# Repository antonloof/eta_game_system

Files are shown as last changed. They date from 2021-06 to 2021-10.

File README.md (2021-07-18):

# Eta game system
Playing games on a wall of TLS3001. Driven by a raspberry pi pico

## important docs
https://github.com/FastLED/FastLED/issues/1

Summary:
Manchester encoded data:
1 => 10
0 => 01
Timing is critical, keep constant period!
When sleeping put data low!

Sync frame: "1"*15+"0001"+"0"*11
(111111111111111000100000000000)

Reset frame: "1"*15 + "0100"
(1111111111111110100)

Data frame header: "1"*15 + "0010" 
(1111111111111110010)

Data content: "0"+"x"*12 + "0"+"x"*12 + "0"+"x"*12
where x is the rgb data to send total 39 bits per led
repeat this for all leds in series

The source:
Data communication protocol: 

Gave SDI input signal pin must follow the following definitions:

a. valid input data must be Manchester encoded signal. 

(from high to low transition indicates "1", from low to high Jump indicates "0")

b. During chip power after a synchronization frame must be sent to the chip detection of communication baud rate. Sync frame

Format is: 15'b111111111111111 + 4' b0001 +11' b00000000000, sending synchronization

Frame must be delayed for some time and then send the data frame, so that each chip can be done in order to accurately detect

To the communication baud rate, delay time (us) greater than: Connection chip count ÷ communication baud rate (MHz) × 30

c. several frames in the transmission data, re-send a reset frame, wait 1ms later, send it again with the

Step frames for the chip to eliminate the accumulated error, reset frame format:

15'b111111111111111 +4' b0100

d. data frame format is: 15'b111111111111111 +4' b0010 (header) + first chip

39bit second chip 39bit data + data + ...... + n-th chip 39bit data

e. first chip is first received data chips, chip data format is: 1 'b0 (identification bits) + 12'

bxxxxxxxxxxxx (output port 1 data) + 1'b0 (flag) + 12'bxxxxxxxxxxxx (input

The port 2 data) + 1'b0 (flag) + 12'bxxxxxxxxxxxx (output port 3 data),

x is 1 or the 0

f. data is first sent MSB (most significant bit)

g. SDI input pin in the idle state, must remain low

h. the same frame data transmission process, must be sent contiguously, in the middle, without interruption, transmission frequency can not be Changed.

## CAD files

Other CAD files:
controller/controller_sw.stp

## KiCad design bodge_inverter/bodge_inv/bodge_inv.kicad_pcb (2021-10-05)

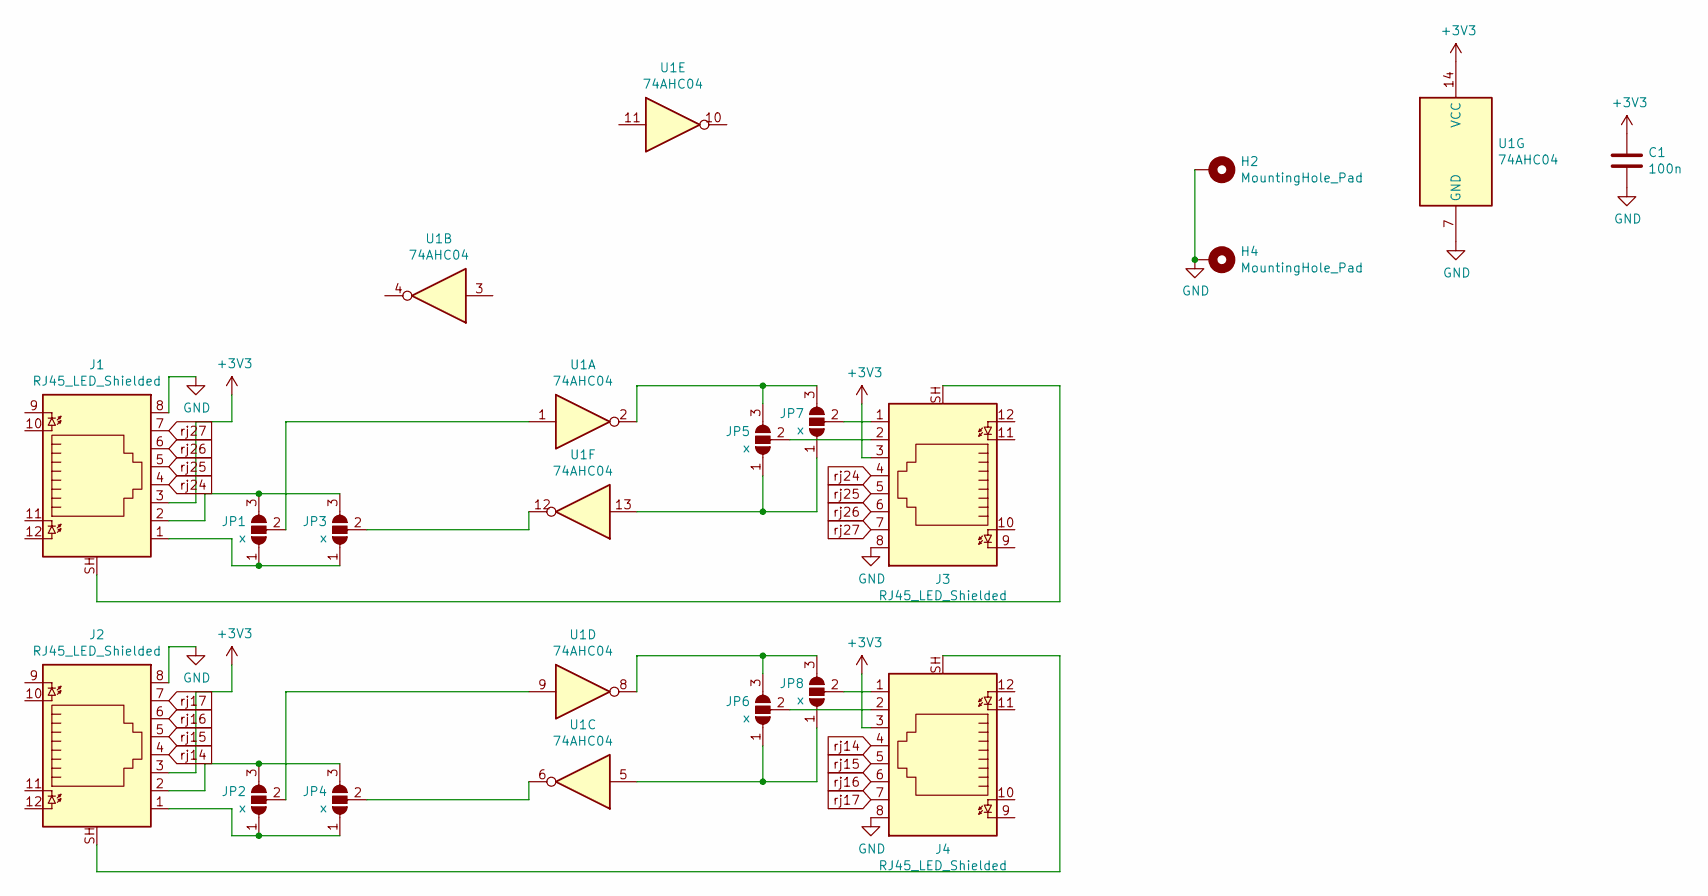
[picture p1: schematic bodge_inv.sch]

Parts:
C1: 100n; C_0603_1608Metric_Pad1.05x0.95mm_HandSolder
H2, H4: MountingHole_Pad; MountingHole_3.2mm_M3_Pad
J1, J2, J3, J4: RJ45_LED_Shielded; RJ45_BEL_SS74301-00x_Vertical
JP1, JP2, JP3, JP4, JP5, JP6, JP7, JP8: x; SolderJumper-3_P1.3mm_Open_Pad1.0x1.5mm_NumberLabels
U1: 74AHC04; SOIC-14_3.9x8.7mm_P1.27mm

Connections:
+3V3: C1.1, J1.3, J2.3, J3.3, J4.3, U1.14 (VCC)
GND: C1.2, H2.1, H4.1, J1.8, J2.8, J3.8, J4.8, U1.7 (GND)
unnamed: J1.1, JP1.1 (A), JP3.1 (A)
unnamed: J1.2, JP1.3 (B), JP3.3 (B)
unnamed: J1.SH, J3.SH
unnamed: J2.1, JP2.1 (A), JP4.1 (A)
unnamed: J2.2, JP2.3 (B), JP4.3 (B)
unnamed: J2.SH, J4.SH
unnamed: J3.1, JP7.2 (C)
unnamed: J3.2, JP5.2 (C)
unnamed: J4.1, JP8.2 (C)
unnamed: J4.2, JP6.2 (C)
unnamed: JP1.2 (C), U1.1
unnamed: JP2.2 (C), U1.9
unnamed: JP3.2 (C), U1.12
unnamed: JP4.2 (C), U1.6
unnamed: JP5.1 (A), JP7.1 (A), U1.13
unnamed: JP5.3 (B), JP7.3 (B), U1.2
unnamed: JP6.1 (A), JP8.1 (A), U1.5
unnamed: JP6.3 (B), JP8.3 (B), U1.8
rj14: J2.4, J4.4
rj15: J2.5, J4.5
rj16: J2.6, J4.6
rj17: J2.7, J4.7
rj24: J1.4, J3.4
rj25: J1.5, J3.5
rj26: J1.6, J3.6
rj27: J1.7, J3.7

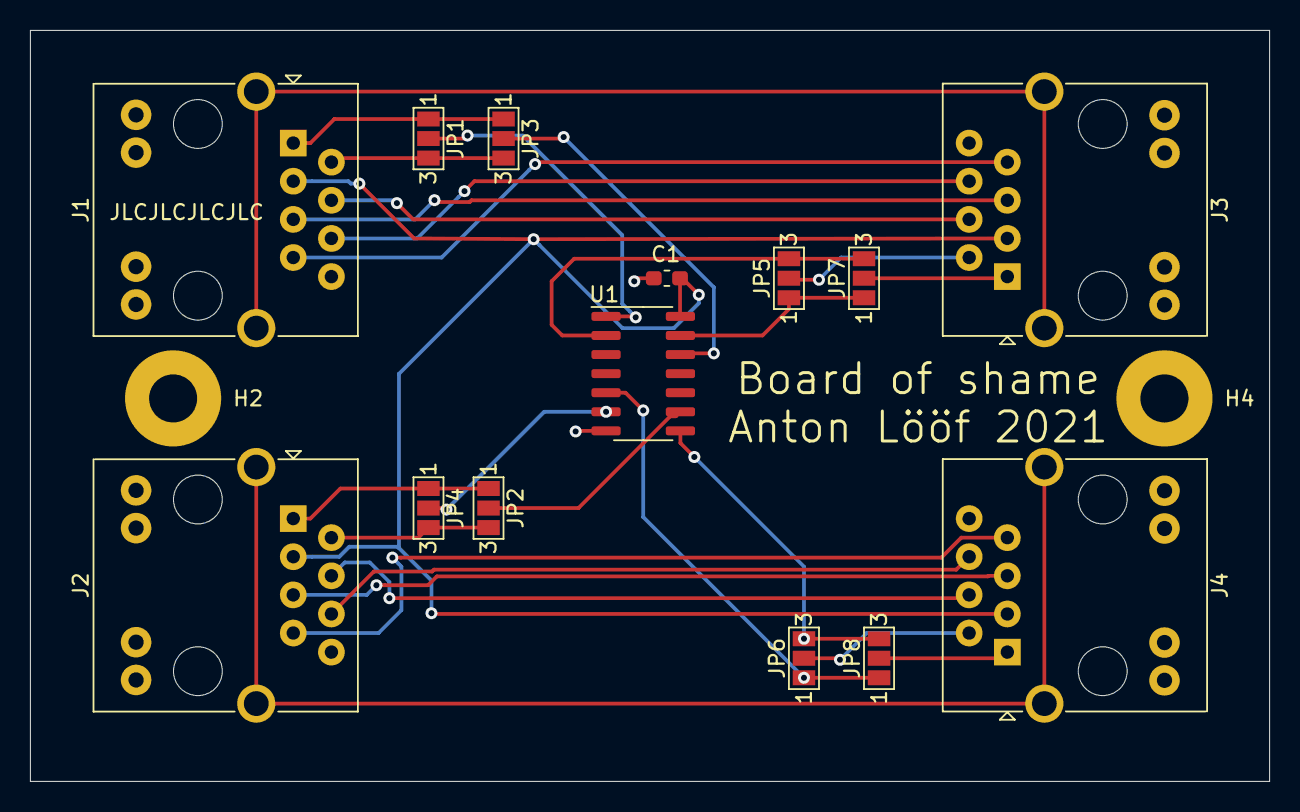
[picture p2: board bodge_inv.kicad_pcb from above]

Board: 2 copper layers, 82.5 x 50.0 mm, 16 parts (0 on the bottom side), 28 nets.

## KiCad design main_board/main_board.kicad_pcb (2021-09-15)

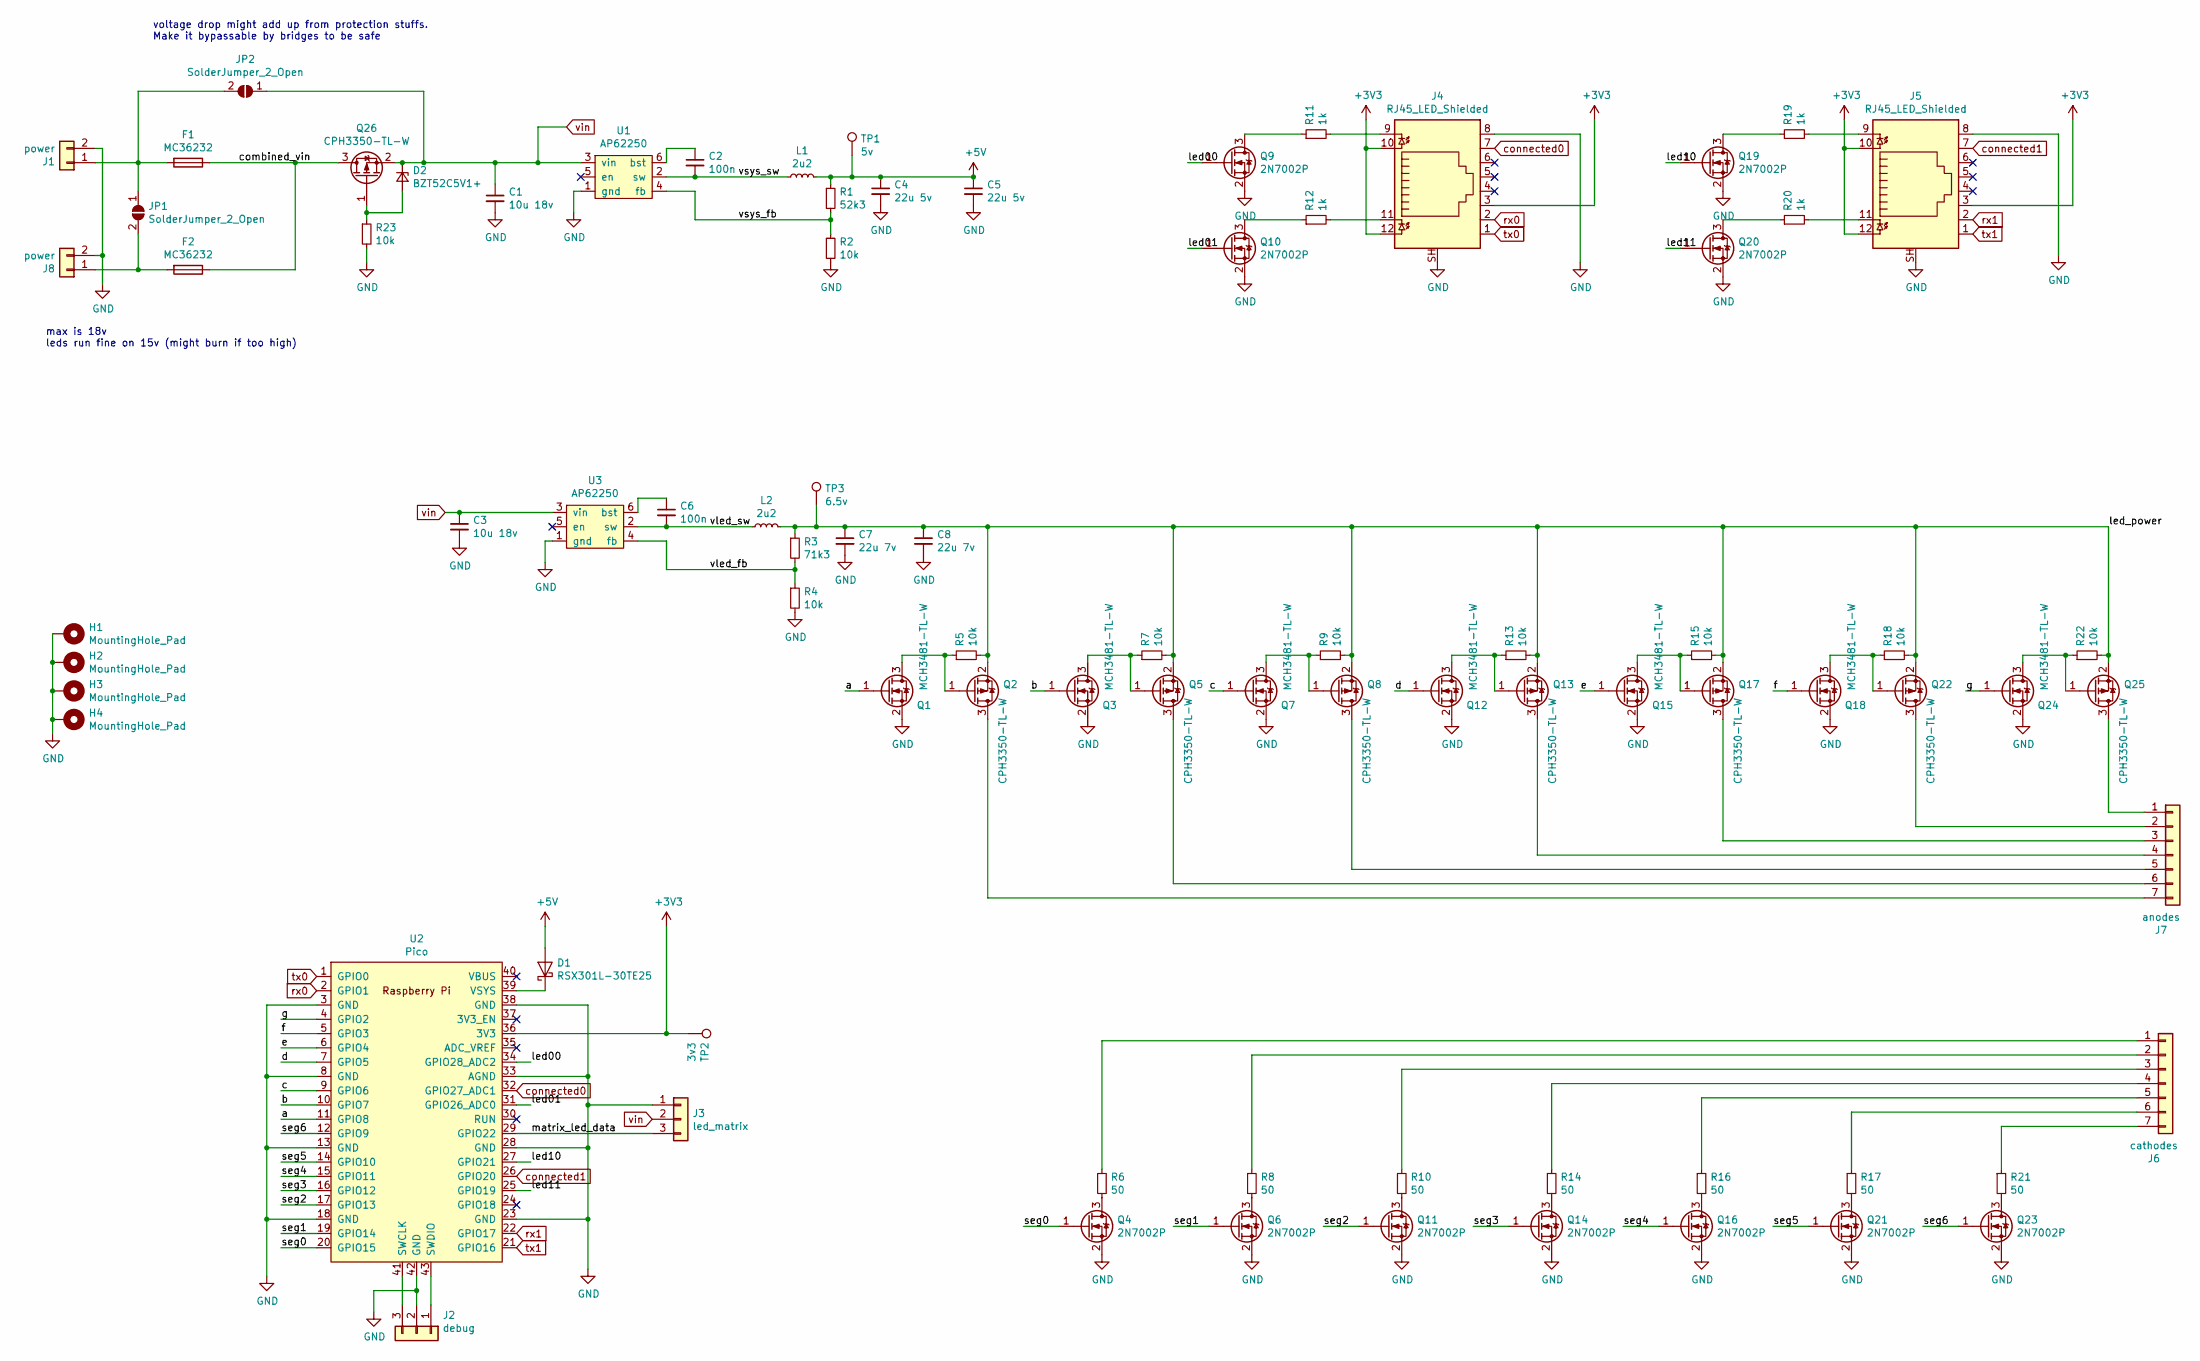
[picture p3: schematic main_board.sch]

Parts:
C1, C3: 10u 18v; C_1206_3216Metric
C2, C6: 100n; C_0603_1608Metric_Pad1.08x0.95mm_HandSolder
C4, C5: 22u 5v; C_0603_1608Metric_Pad1.08x0.95mm_HandSolder
C7, C8: 22u 7v; C_0805_2012Metric_Pad1.18x1.45mm_HandSolder
D1: RSX301L-30TE25; smd_diode_sod_106
D2: BZT52C5V1+; D_SOD-123
F1, F2: MC36232; Fuse_1812_4532Metric_Castellated
H1, H2, H3, H4: MountingHole_Pad; MountingHole_3.2mm_M3_Pad_TopBottom
J1, J8: power; TerminalBlock_Phoenix_MKDS-1,5-2_1x02_P5.00mm_Horizontal
J2: debug; PinHeader_1x03_P2.54mm_Vertical
J3: led_matrix; TerminalBlock_Phoenix_MKDS-1,5-3_1x03_P5.00mm_Horizontal
J4, J5: RJ45_LED_Shielded; RJ45_BEL_SS74301-00x_Vertical
J6: cathodes; PinHeader_1x07_P2.54mm_Vertical
J7: anodes; PinHeader_1x07_P2.54mm_Vertical
JP1, JP2: SolderJumper_2_Open; SolderJumper-2_P1.3mm_Open_TrianglePad1.0x1.5mm
L1, L2: 2u2; smd_inductor_0806_2016metric
Q1, Q3, Q7, Q12, Q15, Q18, Q24: MCH3481-TL-W; SOT-323_SC-70_Handsoldering
Q2, Q5, Q8, Q13, Q17, Q22, Q25, Q26: CPH3350-TL-W; SOT-23_Handsoldering
Q4, Q6, Q9, Q10, Q11, Q14, Q16, Q19, Q20, Q21, Q23: 2N7002P; SOT-23_Handsoldering
R1: 52k3; R_0603_1608Metric_Pad0.98x0.95mm_HandSolder
R2, R4, R5, R7, R9, R13, R15, R18, R22, R23: 10k; R_0603_1608Metric_Pad0.98x0.95mm_HandSolder
R3: 71k3; R_0603_1608Metric_Pad0.98x0.95mm_HandSolder
R6, R8, R10, R14, R16, R17, R21: 50; R_0603_1608Metric_Pad0.98x0.95mm_HandSolder
R11, R12, R19, R20: 1k; R_0603_1608Metric_Pad0.98x0.95mm_HandSolder
TP1: 5v; TestPoint_Pad_D1.5mm
TP2: 3v3; TestPoint_Pad_D1.5mm
TP3: 6.5v; TestPoint_Pad_D1.5mm
U1, U3: AP62250; TSOT-23-6
U2: Pico; RPi_Pico_SMD_TH

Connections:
+3V3: J4.3, J4.10, J4.12, J5.3, J5.10, J5.12, TP2.1, U2.36 (3V3)
+5V: C4.1, C5.1, D1.2 (A), L1.2, R1.1, TP1.1
/a: Q1.1 (G), U2.11 (GPIO8)
/b: Q3.1 (G), U2.10 (GPIO7)
/c: Q7.1 (G), U2.9 (GPIO6)
/combined_vin: F1.1, F2.1, Q26.3 (D)
/d: Q12.1 (G), U2.7 (GPIO5)
/e: Q15.1 (G), U2.6 (GPIO4)
/f: Q18.1 (G), U2.5 (GPIO3)
/g: Q24.1 (G), U2.4 (GPIO2)
/led00: Q9.1 (G), U2.34 (GPIO28_ADC2)
/led01: Q10.1 (G), U2.31 (GPIO26_ADC0)
/led10: Q19.1 (G), U2.27 (GPIO21)
/led11: Q20.1 (G), U2.25 (GPIO19)
/led_power: C7.1, C8.1, L2.2, Q2.2 (S), Q5.2 (S), Q8.2 (S), Q13.2 (S), Q17.2 (S), Q22.2 (S), Q25.2 (S), R3.1, R5.2, R7.2, R9.2, R13.2, R15.2, R18.2, R22.2, TP3.1
/matrix_led_data: J3.3, U2.29 (GPIO22)
/seg0: Q4.1 (G), U2.20 (GPIO15)
/seg1: Q6.1 (G), U2.19 (GPIO14)
/seg2: Q11.1 (G), U2.17 (GPIO13)
/seg3: Q14.1 (G), U2.16 (GPIO12)
/seg4: Q16.1 (G), U2.15 (GPIO11)
/seg5: Q21.1 (G), U2.14 (GPIO10)
/seg6: Q23.1 (G), U2.12 (GPIO9)
/vled_fb: R3.2, R4.1, U3.4 (fb)
/vled_sw: C6.2, L2.1, U3.2 (sw)
/vsys_fb: R1.2, R2.1, U1.4 (fb)
/vsys_sw: C2.2, L1.1, U1.2 (sw)
GND: C1.2, C3.2, C4.2, C5.2, C7.2, C8.2, H1.1, H2.1, H3.1, H4.1, J1.2, J2.2, J3.1, J4.8, J4.SH, J5.8, J5.SH, J8.2, Q1.2 (S), Q3.2 (S), Q4.2 (S), Q6.2 (S), Q7.2 (S), Q9.2 (S), Q10.2 (S), Q11.2 (S), Q12.2 (S), Q14.2 (S), Q15.2 (S), Q16.2 (S), Q18.2 (S), Q19.2 (S), Q20.2 (S), Q21.2 (S), Q23.2 (S), Q24.2 (S), R2.2, R4.2, R23.2, U1.1 (gnd), U2.3 (GND), U2.8 (GND), U2.13 (GND), U2.18 (GND), U2.23 (GND), U2.28 (GND), U2.33 (AGND), U2.38 (GND), U2.42 (GND), U3.1 (gnd)
unnamed: C2.1, U1.6 (bst)
unnamed: C6.1, U3.6 (bst)
unnamed: D1.1 (K), U2.39 (VSYS)
unnamed: D2.2 (A), Q26.1 (G), R23.1
unnamed: F1.2, J1.1, JP1.1 (A), JP2.2 (B)
unnamed: F2.2, J8.1, JP1.2 (B)
unnamed: J2.1, U2.43 (SWDIO)
unnamed: J2.3, U2.41 (SWCLK)
unnamed: J4.9, R11.2
unnamed: J4.11, R12.2
unnamed: J5.9, R19.2
unnamed: J5.11, R20.2
unnamed: J6.1, R6.1
unnamed: J6.2, R8.1
unnamed: J6.3, R10.1
unnamed: J6.4, R14.1
unnamed: J6.5, R16.1
unnamed: J6.6, R17.1
unnamed: J6.7, R21.1
unnamed: J7.1, Q25.3 (D)
unnamed: J7.2, Q22.3 (D)
unnamed: J7.3, Q17.3 (D)
unnamed: J7.4, Q13.3 (D)
unnamed: J7.5, Q8.3 (D)
unnamed: J7.6, Q5.3 (D)
unnamed: J7.7, Q2.3 (D)
unnamed: Q1.3 (D), Q2.1 (G), R5.1
unnamed: Q3.3 (D), Q5.1 (G), R7.1
unnamed: Q4.3 (D), R6.2
unnamed: Q6.3 (D), R8.2
unnamed: Q7.3 (D), Q8.1 (G), R9.1
unnamed: Q9.3 (D), R11.1
unnamed: Q10.3 (D), R12.1
unnamed: Q11.3 (D), R10.2
unnamed: Q12.3 (D), Q13.1 (G), R13.1
unnamed: Q14.3 (D), R14.2
unnamed: Q15.3 (D), Q17.1 (G), R15.1
unnamed: Q16.3 (D), R16.2
unnamed: Q18.3 (D), Q22.1 (G), R18.1
unnamed: Q19.3 (D), R19.1
unnamed: Q20.3 (D), R20.1
unnamed: Q21.3 (D), R17.2
unnamed: Q23.3 (D), R21.2
unnamed: Q24.3 (D), Q25.1 (G), R22.1
connected0: J4.7, U2.32 (GPIO27_ADC1)
connected1: J5.7, U2.26 (GPIO20)
rx0: J4.2, U2.2 (GPIO1)
rx1: J5.2, U2.22 (GPIO17)
tx0: J4.1, U2.1 (GPIO0)
tx1: J5.1, U2.21 (GPIO16)
vin: C1.1, C3.1, D2.1 (K), J3.2, JP2.1 (A), Q26.2 (S), U1.3 (vin), U3.3 (vin)

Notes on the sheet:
max is 18v leds run fine on 15v (might burn if too high)
voltage drop might add up from protection stuffs. Make it bypassable by bridges to be safe

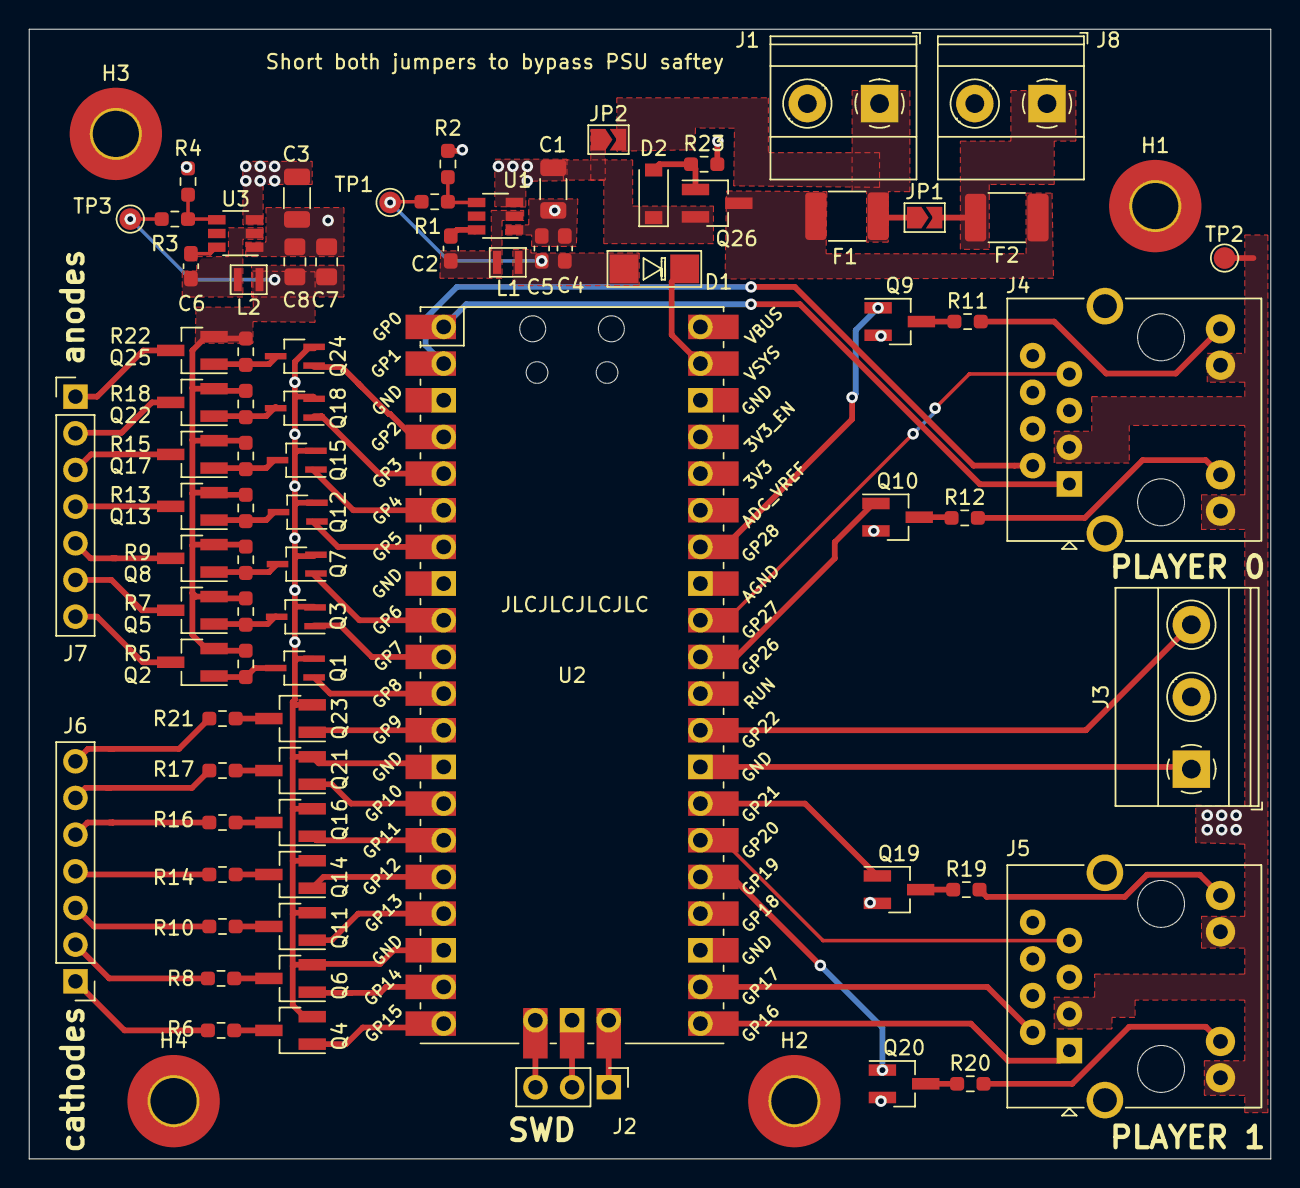
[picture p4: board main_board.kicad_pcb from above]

Board: 2 copper layers, 86.0 x 78.2 mm, 83 parts (0 on the bottom side), 79 nets.

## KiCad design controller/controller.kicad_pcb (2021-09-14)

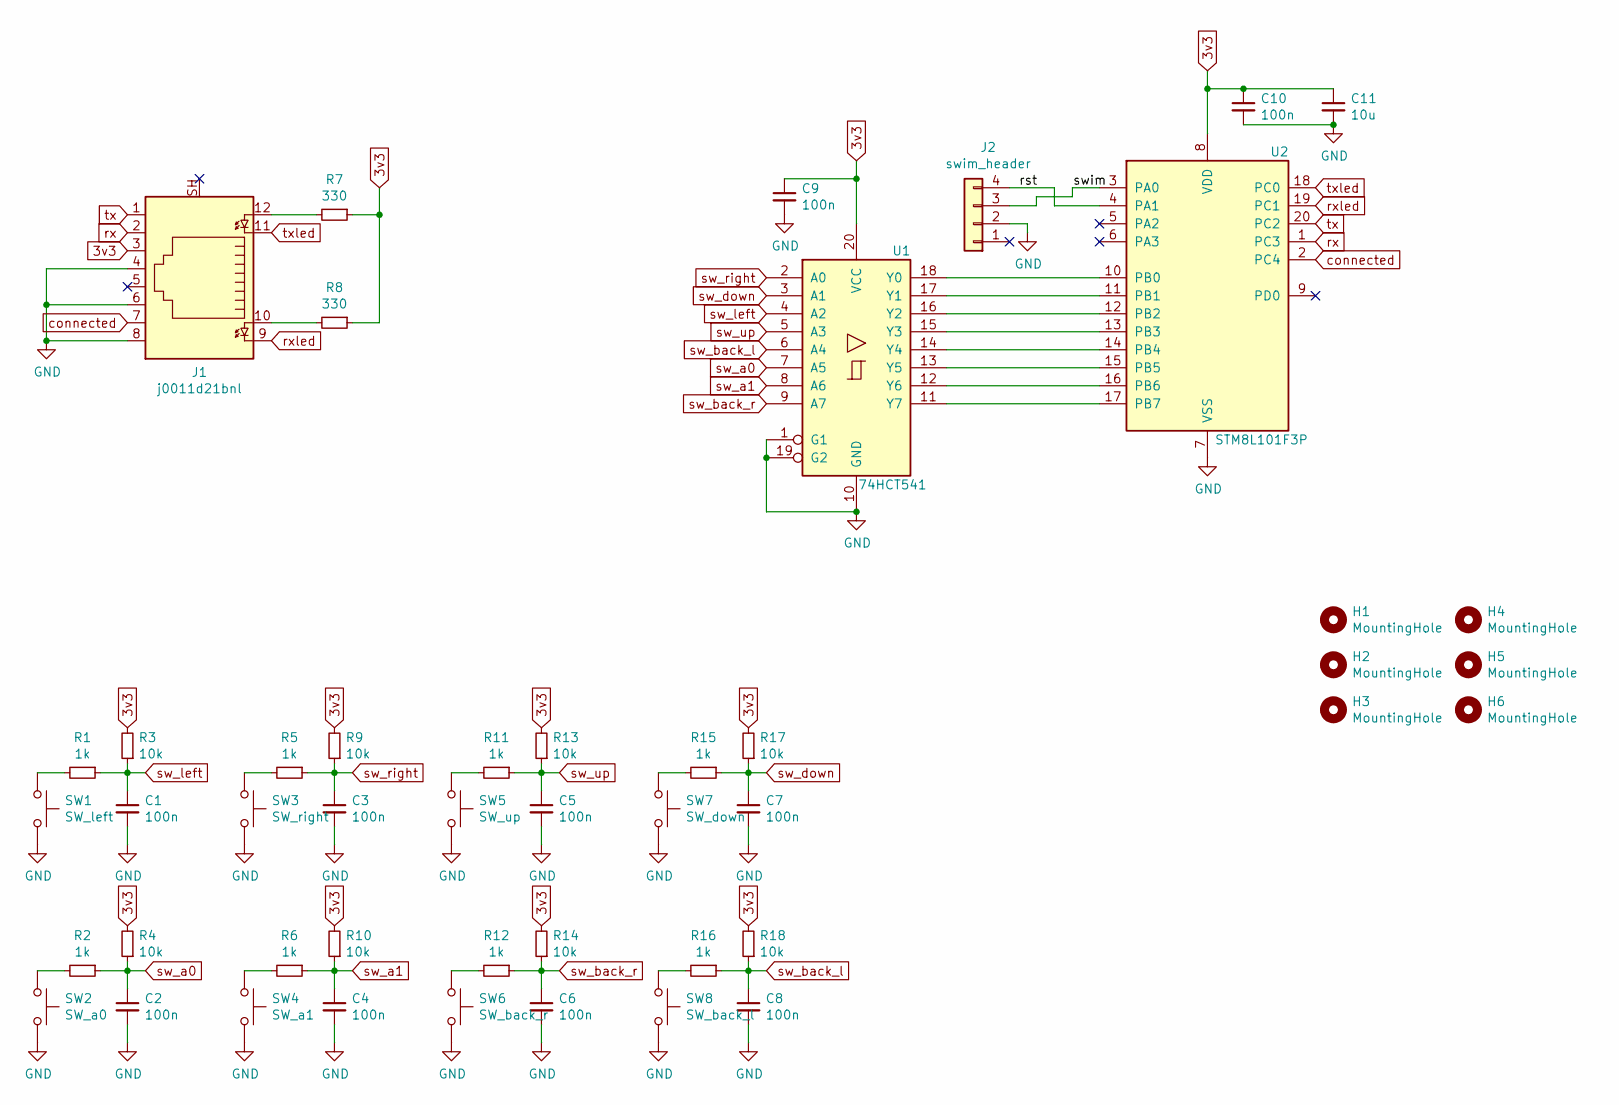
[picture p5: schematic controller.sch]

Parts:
C1, C2, C3, C4, C5, C6, C7, C8, C9, C10: 100n; C_0603_1608Metric_Pad1.08x0.95mm_HandSolder
C11: 10u; C_0603_1608Metric_Pad1.08x0.95mm_HandSolder
H1, H2, H3, H4, H5, H6: MountingHole; MountingHole_3.2mm_M3
J1: j0011d21bnl; RJ45_BEL_SS74301-00x_Vertical
J2: swim_header; TSM-104-01-L-SH
R1, R2, R5, R6, R11, R12, R15, R16: 1k; R_0603_1608Metric_Pad0.98x0.95mm_HandSolder
R3, R4, R9, R10, R13, R14, R17, R18: 10k; R_0603_1608Metric_Pad0.98x0.95mm_HandSolder
R7, R8: 330; R_0603_1608Metric_Pad0.98x0.95mm_HandSolder
SW1: SW_left; SW_Cherry_MX_1.00u_Plate
SW2: SW_a0; SW_Cherry_MX_1.00u_Plate
SW3: SW_right; SW_Cherry_MX_1.00u_Plate
SW4: SW_a1; SW_Cherry_MX_1.00u_Plate
SW5: SW_up; SW_Cherry_MX_1.00u_Plate
SW6: SW_back_r; TSM-102-01-l_SH
SW7: SW_down; SW_Cherry_MX_1.00u_Plate
SW8: SW_back_l; TSM-102-01-l_SH
U1: 74HCT541; TSSOP-20_4.4x6.5mm_P0.65mm
U2: STM8L101F3P; TSSOP-20_4.4x6.5mm_P0.65mm

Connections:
3v3: C9.1, C10.1, C11.1, J1.3, R3.2, R4.2, R7.1, R8.1, R9.2, R10.2, R13.2, R14.2, R17.2, R18.2, U1.20 (VCC), U2.8 (VDD)
/rst: J2.4, U2.4 (PA1)
/swim: J2.3, U2.3 (PA0)
GND: C1.2, C2.2, C3.2, C4.2, C5.2, C6.2, C7.2, C8.2, C9.2, C10.2, C11.2, J1.4, J1.6, J1.8, J2.2, SW1.2, SW2.2, SW3.2, SW4.2, SW5.2, SW6.2, SW7.2, SW8.2, U1.1 (G1), U1.10 (GND), U1.19 (G2), U2.7 (VSS)
unnamed: J1.10, R8.2
unnamed: J1.12, R7.2
unnamed: R1.2, SW1.1
unnamed: R2.2, SW2.1
unnamed: R5.2, SW3.1
unnamed: R6.2, SW4.1
unnamed: R11.2, SW5.1
unnamed: R12.2, SW6.1
unnamed: R15.2, SW7.1
unnamed: R16.2, SW8.1
unnamed: U1.11 (Y7), U2.17 (PB7)
unnamed: U1.12 (Y6), U2.16 (PB6)
unnamed: U1.13 (Y5), U2.15 (PB5)
unnamed: U1.14 (Y4), U2.14 (PB4)
unnamed: U1.15 (Y3), U2.13 (PB3)
unnamed: U1.16 (Y2), U2.12 (PB2)
unnamed: U1.17 (Y1), U2.11 (PB1)
unnamed: U1.18 (Y0), U2.10 (PB0)
connected: J1.7, U2.2 (PC4)
rx: J1.2, U2.1 (PC3)
rxled: J1.9, U2.19 (PC1)
sw_a0: C2.1, R2.1, R4.1, U1.7 (A5)
sw_a1: C4.1, R6.1, R10.1, U1.8 (A6)
sw_back_l: C8.1, R16.1, R18.1, U1.6 (A4)
sw_back_r: C6.1, R12.1, R14.1, U1.9 (A7)
sw_down: C7.1, R15.1, R17.1, U1.3 (A1)
sw_left: C1.1, R1.1, R3.1, U1.4 (A2)
sw_right: C3.1, R5.1, R9.1, U1.2 (A0)
sw_up: C5.1, R11.1, R13.1, U1.5 (A3)
tx: J1.1, U2.20 (PC2)
txled: J1.11, U2.18 (PC0)

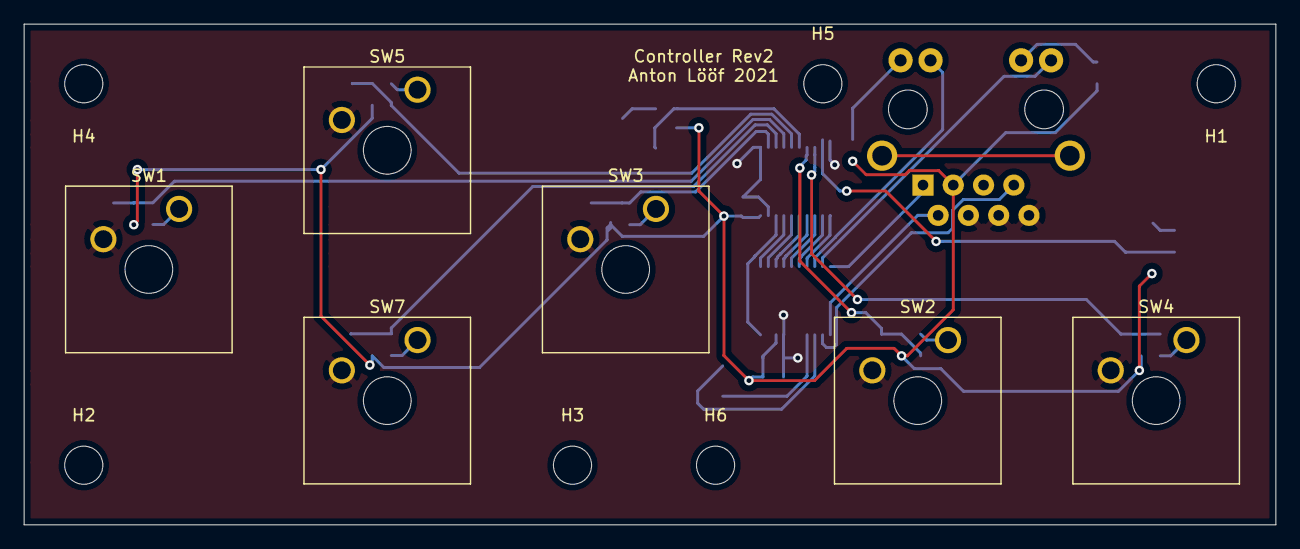
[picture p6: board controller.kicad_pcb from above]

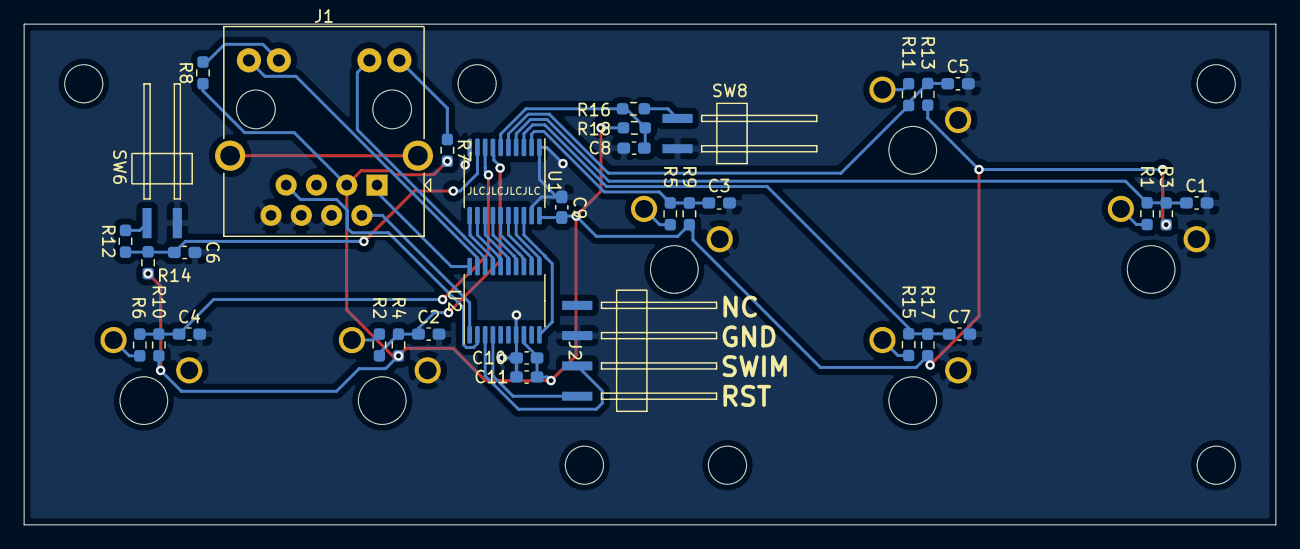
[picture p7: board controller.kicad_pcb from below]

Board: 2 copper layers, 105.0 x 42.0 mm, 47 parts (35 on the bottom side), 35 nets.

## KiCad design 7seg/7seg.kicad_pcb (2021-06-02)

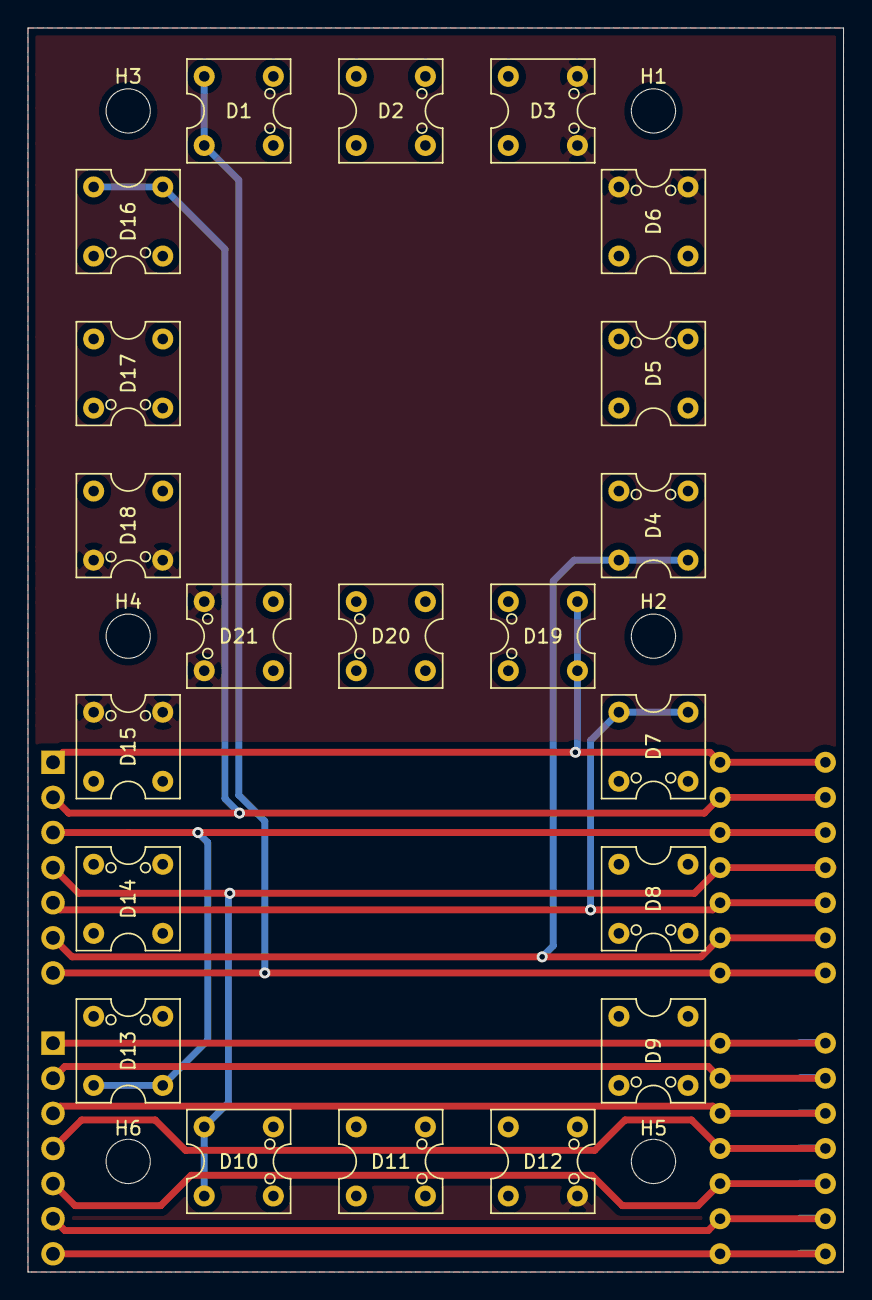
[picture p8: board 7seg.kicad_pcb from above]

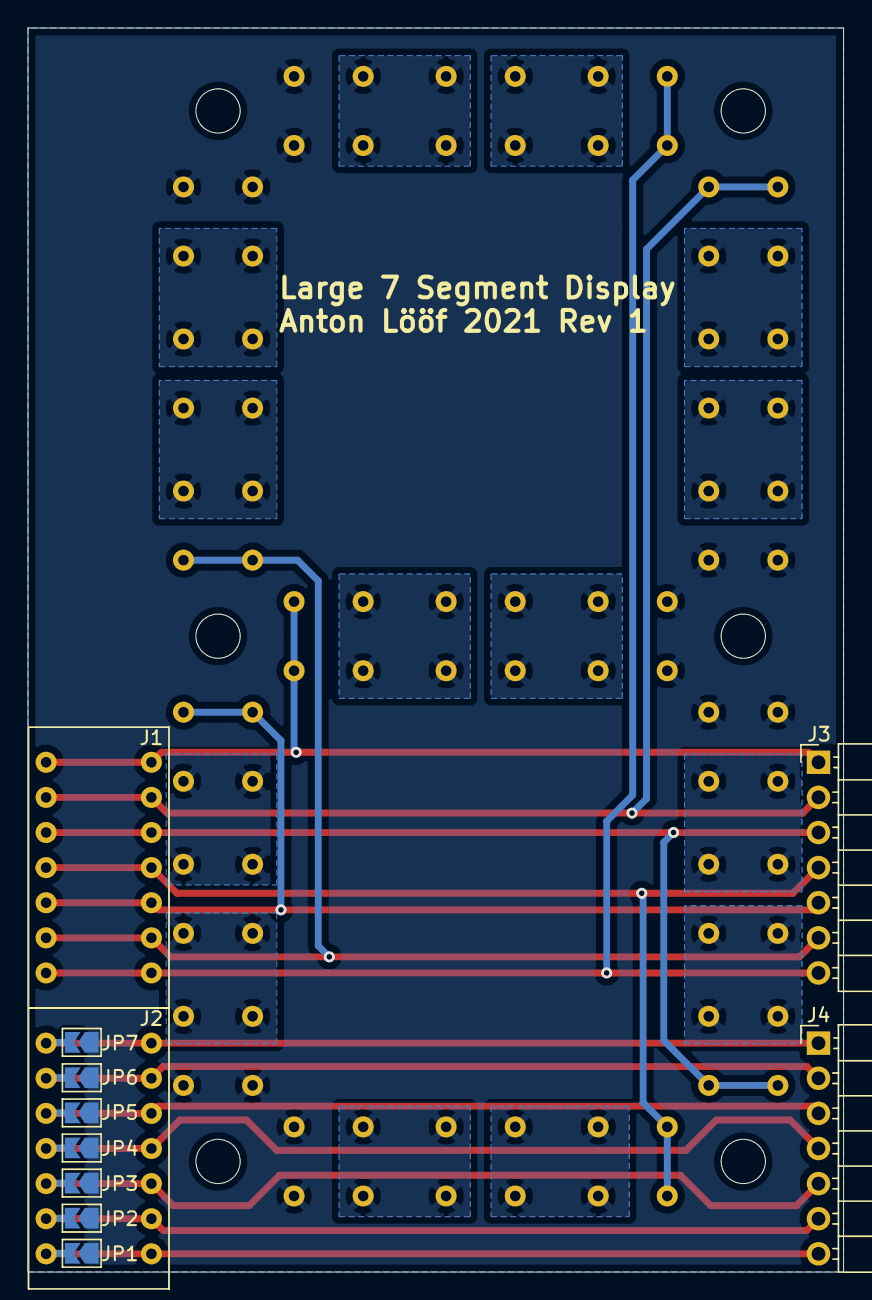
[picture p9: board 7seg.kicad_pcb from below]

Board: 2 copper layers, 59.0 x 90.0 mm, 38 parts (11 on the bottom side), 29 nets.

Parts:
D1, D2, D3, D4, D5, D6, D7, D8, D9, D10, D11, D12, D13, D14, D15, D16, D17, D18, D19, D20, D21: led4pin
H1, H2, H3, H4, H5, H6: MountingHole; MountingHole_3.2mm_M3
J1, J2: Conn_01x07; pin-socket-7x2.54
J3, J4: Conn_01x07; PinHeader_1x07_P2.54mm_Horizontal
JP1, JP2, JP3, JP4, JP5, JP6, JP7: SolderJumper_2_Bridged; SolderJumper-2_P1.3mm_Open_TrianglePad1.0x1.5mm

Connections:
/com: D3.1, D3.3, D6.1, D6.3, D9.1, D9.3, D12.1, D12.3, D15.1, D15.3, D18.1, D18.3, D21.1, D21.3, JP1.1, JP2.1, JP3.1, JP4.1, JP5.1, JP6.1, JP7.1
unnamed: D1.1, D1.3, D2.2, D2.4
unnamed: D2.1, D2.3, D3.2, D3.4
unnamed: D4.1, D4.3, D5.2, D5.4
unnamed: D5.1, D5.3, D6.2, D6.4
unnamed: D7.1, D7.3, D8.2, D8.4
unnamed: D8.1, D8.3, D9.2, D9.4
unnamed: D10.1, D10.3, D11.2, D11.4
unnamed: D11.1, D11.3, D12.2, D12.4
unnamed: D13.1, D13.3, D14.2, D14.4
unnamed: D14.1, D14.3, D15.2, D15.4
unnamed: D16.1, D16.3, D17.2, D17.4
unnamed: D17.1, D17.3, D18.2, D18.4
unnamed: D19.1, D19.3, D20.2, D20.4
unnamed: D20.1, D20.3, D21.2, D21.4
a: D1.2, D1.4, J1.7, J3.7
b: D4.2, D4.4, J1.6, J3.6
b0: J2.7, J4.7, JP1.2
b1: J2.6, J4.6, JP2.2
b2: J2.5, J4.5, JP3.2
b3: J2.4, J4.4, JP4.2
b4: J2.3, J4.3, JP5.2
b5: J2.2, J4.2, JP6.2
b6: J2.1, J4.1, JP7.2
c: D7.2, D7.4, J1.5, J3.5
d: D10.2, D10.4, J1.4, J3.4
e: D13.2, D13.4, J1.3, J3.3
f: D16.2, D16.4, J1.2, J3.2
g: D19.2, D19.4, J1.1, J3.1

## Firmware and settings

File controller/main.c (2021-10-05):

#include "stm8l101f3.h" 

#define DEBUONCE_THRESH 100

unsigned char received, last_received;

int count = 0;
int has_send = 1;

main()
{
	sfr_CLK.CKDIVR.byte = 0; // FULL SPEED
	sfr_CLK.PCKENR.byte = 0xFF; // enable all (usart)

	// PC0 and PC1 push pull for leds (does not work, are OD only)
	// PC4 should output a "high" all the time
	// PC3 is tx and should be output, push pull, high speed
	// PC2 is rx and should be input no interrupt
	sfr_PORTC.DDR.byte = 0b00011011;
	sfr_PORTC.CR1.C10 = 1; // push pull
	sfr_PORTC.CR1.C11 = 1; // push pull
	sfr_PORTC.CR1.C13 = 1; // push pull
	sfr_PORTC.CR1.C14 = 1; // push pull
	sfr_PORTC.CR2.C23 = 1; // high speed
	
	// port b is all inputs with pullups. 
	sfr_PORTB.DDR.byte = 0;
	sfr_PORTB.CR1.byte = 0xFF;
	sfr_PORTB.CR2.byte = 0;
	
	
	// configure usart
	sfr_USART.CR1.USARTD = 0; // dont disable
	sfr_USART.CR1.MSL = 0; // 8 bit bytes
	sfr_USART.CR3.STOP = 0; // 1 stop bit

	// baudrate 16Mhz/115200 baud ~= 139 = 0x008B
	// bbr2 should be written to first, update on brr1 write
	sfr_USART.BRR2.byte = 0x0B;
	sfr_USART.BRR1.byte = 0x08;
	
	sfr_USART.CR2.TEN = 1; // enable transmitter
	
	// the controller is connected
	sfr_PORTC.ODR.ODR4 = 1;
	
	last_received = sfr_PORTB.IDR.byte;
	while (1) {
		received = sfr_PORTB.IDR.byte;

		if (!has_send) {
			if (received == last_received) {
				count++;
				if (count == DEBUONCE_THRESH) {
					count = 0;
					has_send = 1;
					while (!sfr_USART.SR.TXE);
					sfr_USART.DR.byte = received;
				}
			} else {
				count = 0;
			}
		} else {
			if (received != last_received) {
				has_send = 0;
			}
		}
		last_received = received;
	}
}

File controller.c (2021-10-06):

#include "controller.h"

void controller_uart0_irq();
void controller_uart1_irq();
void controller_uart_irq(controller *ctl);

void controller_callback_nop(uint8_t d);

controller player0 = {controller_callback_nop, 0, 1, 0, uart0, UART0_IRQ, controller_uart0_irq};
controller player1 = {controller_callback_nop, 1, 17, 16, uart1, UART1_IRQ, controller_uart1_irq};

void controller_init(controller_callback callback, controller *out)
{
    uart_init(out->uart, 115200);
    uart_set_hw_flow(out->uart, false, false);
    uart_set_format(out->uart, 8, 1, UART_PARITY_NONE);
    uart_set_translate_crlf(out->uart, false);
    uart_set_fifo_enabled(out->uart, false);

    out->callback = callback;

    gpio_set_function(out->rxpin, GPIO_FUNC_UART);
    gpio_set_function(out->txpin, GPIO_FUNC_UART);
    // rx interrupts

    irq_set_exclusive_handler(out->irq_flag, out->irq_happened);
    irq_set_enabled(out->irq_flag, true);
    uart_set_irq_enables(out->uart, true, false);
}

void controller_callback_nop(uint8_t d) {}

void controller_send(controller *ctl, uint8_t data)
{
    uart_putc_raw(ctl->uart, data);
}

void controller_uart0_irq()
{
    controller_uart_irq(&player0);
}

void controller_uart1_irq()
{
    controller_uart_irq(&player1);
}

void controller_uart_irq(controller *ctl)
{
    while (uart_is_readable(ctl->uart))
    {
        uint8_t ch = uart_getc(ctl->uart);
        ctl->callback(ch);
    }
}

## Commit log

2021-05-22 Work around with DMA
2021-05-26 Now with 100% more dma blinking
2021-06-01 Add 7seg display pcb
    [7seg.kicad_pcb, 7seg.sch]
2021-06-02 rev 1 of 7seg
    [7seg.kicad_pcb, 7seg.sch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]
2021-07-18 Add controller pcb rev1
    [controller-F_Cu.dxf, controller.kicad_pcb, controller.sch]
2021-07-19 Remove bs file
    [controller-F_Cu.dxf]
2021-08-08 Now with extra leds for secondary screens
    [controller.kicad_pcb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]
2021-08-08 Update footprint for controller buffer
    [controller.sch]
2021-08-09 now without speakers now with fets for 7seg
    [main_board.kicad_pcb, main_board.sch]
2021-08-10 Finalize schematic
    [main_board.sch]
2021-08-14 Move extra leds logic to own files
    also make secondary displays "work" needs some more integration tho
2021-08-16 start main board pcb
    [main_board.sch]
2021-08-16 Main board pcb rev1 done and ordered
    [main_board.kicad_pcb, main_board.sch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]
2021-08-29 Fix error in schema
    burned 4 regulatorsy
    [main_board.sch]
2021-08-29 Rev2 of pcb that does not burn regulators
    [main_board.kicad_pcb]
2021-08-30 Add ctrl sw
    found issue with leds on rj45
    might have problems with uart pins in rj45
    [controller.sch]
2021-09-03 Rev 2 controller PCB
    Now uses correct rj45 footprint.
    Leds should work!
    Added 1 more mounting hole (H5)
    [controller.kicad_pcb, controller.sch]
2021-09-14 Controller code and update pmos
    [controller_sw.stp, main_board.sch]
2021-09-15 refactoring and segment
    [main_board.kicad_pcb, main_board.sch]
2021-10-03 7seg works on thing that is put together
    [controller_sw.stp]
2021-10-05 Add bodge board ....
    also controller is good
    [bodge_inv.kicad_pcb, bodge_inv.sch]
2021-10-06 Is wurkin!
    missing one DC DC conv and mounting on wall
    [controller.c, pico_test.c]
